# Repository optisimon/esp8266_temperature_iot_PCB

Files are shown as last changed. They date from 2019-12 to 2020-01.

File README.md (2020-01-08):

# esp8266_temperature_iot_PCB

This is the PCB portion of the temperature plotting iot project.

Project homepage: https://optisimon.com/esp8266/arduino/temperature/monitoring/2020/01/07/esp8266-temperature-plotting-iot/

Software portion: https://github.com/optisimon/esp8266_temperature_iot

Hardware portion: https://github.com/optisimon/esp8266_temperature_iot_PCB/

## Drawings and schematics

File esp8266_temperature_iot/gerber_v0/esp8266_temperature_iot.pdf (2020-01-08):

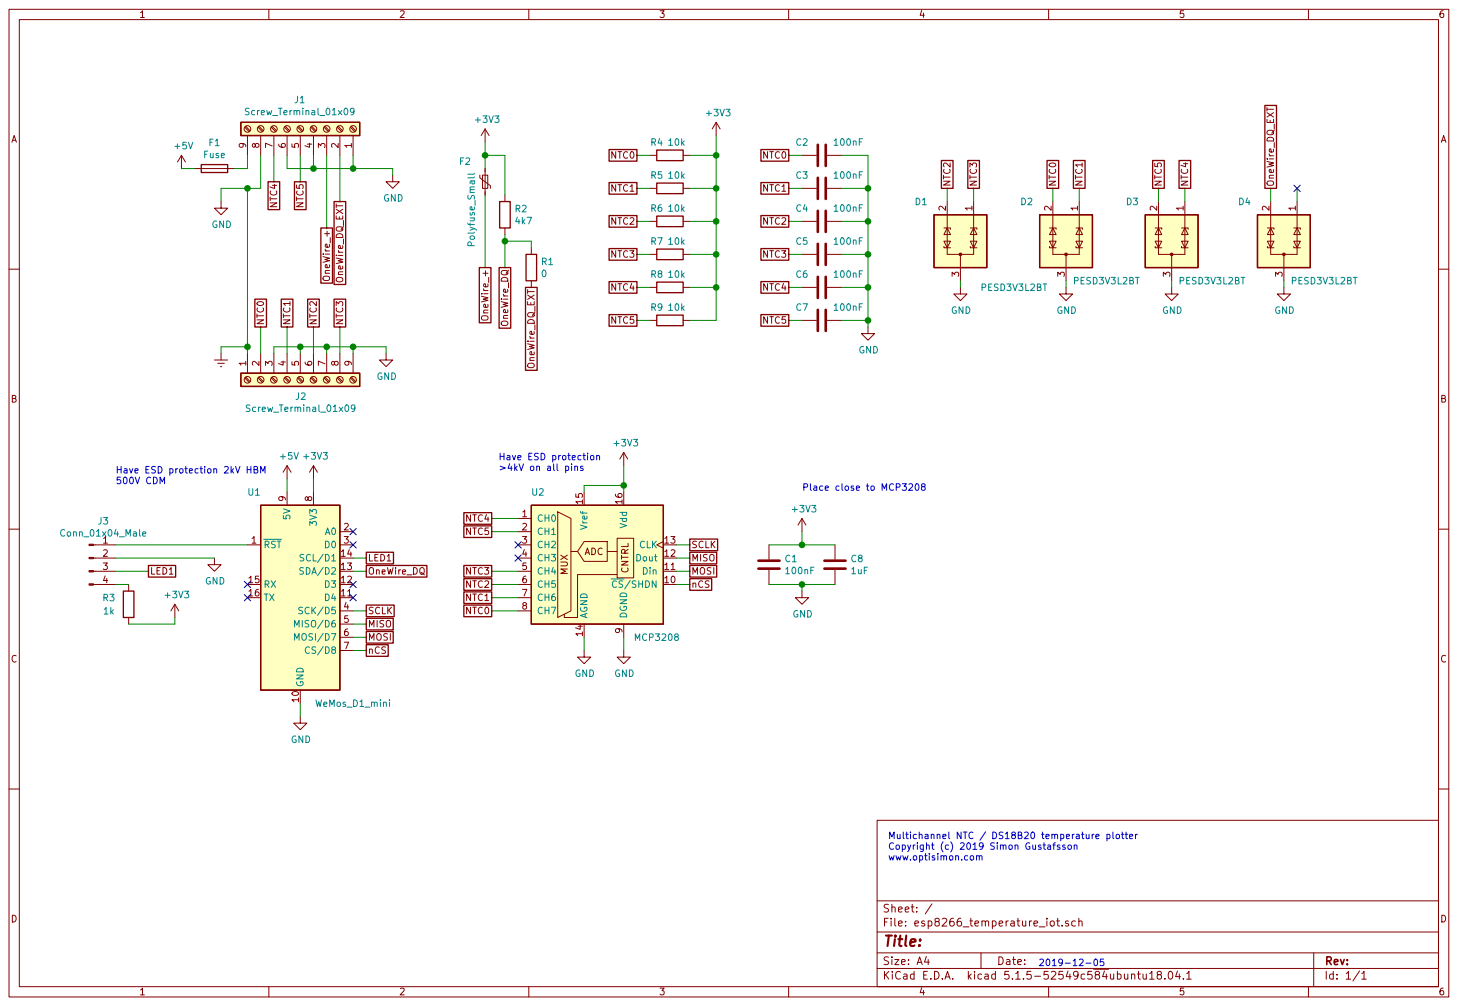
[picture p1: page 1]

Place close to MCP3208 Have ESD protection 2kV HBM
500V CDM

Multichannel NTC / DS18B20 temperature plotter
Copyright (c) 2019 Simon Gustafsson
www.optisimon.com

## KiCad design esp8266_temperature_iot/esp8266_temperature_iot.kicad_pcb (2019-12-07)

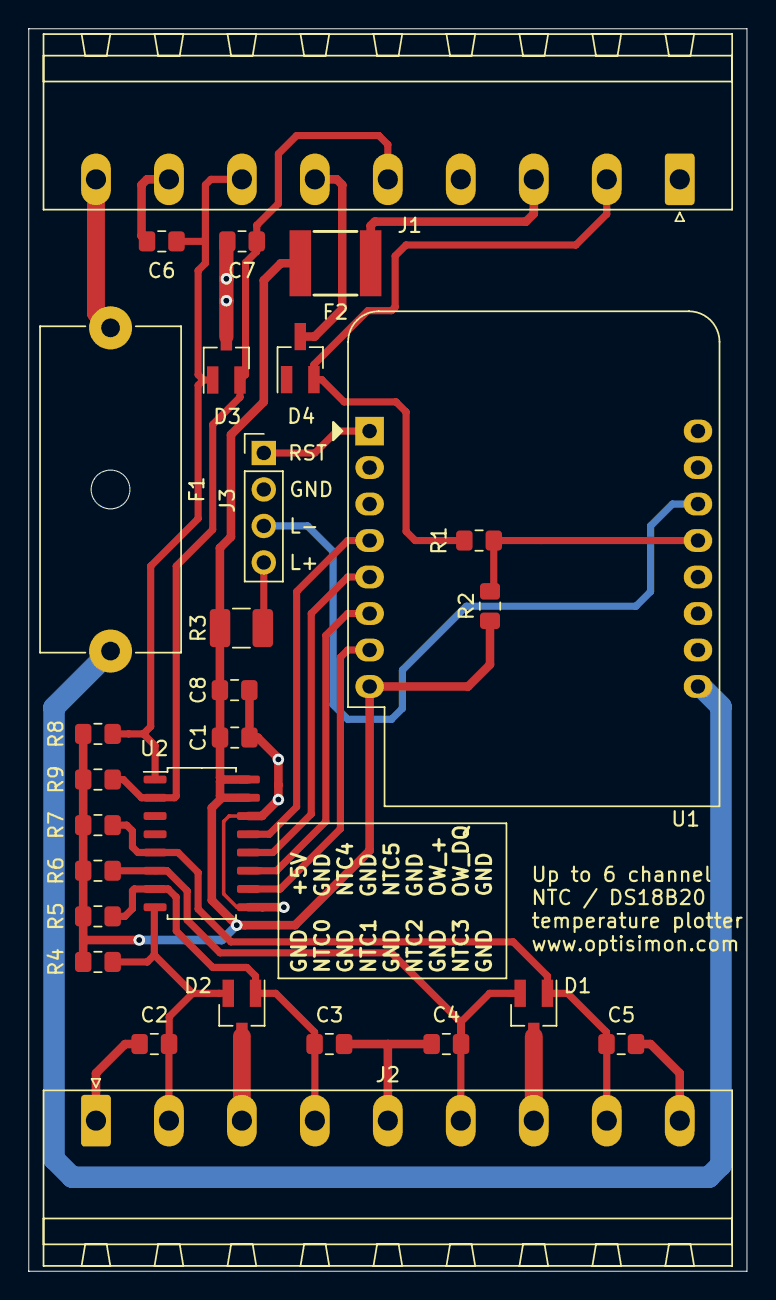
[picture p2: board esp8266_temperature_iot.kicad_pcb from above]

Board: 2 copper layers, 50.0 x 86.5 mm, 28 parts (0 on the bottom side), 20 nets.

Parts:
C1, C2, C3, C4, C5, C6, C7: 100nF; C_0805_2012Metric_Pad1.15x1.40mm_HandSolder
C8: 1uF; C_0805_2012Metric_Pad1.15x1.40mm_HandSolder
D1, D2, D3, D4: PESD3V3L2BT; SOT-23_Handsoldering
F1: Fuse; Fuseholder_Cylinder-5x20mm_Schurter_0031_8201_Horizontal_Op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
F2: Polyfuse_Small; Fuse_Littlefuse-2016L
J1, J2: Screw_Terminal_01x09; PhoenixContact_MSTBA_2,5_9-G-5,08_1x09_P5.08mm_Horizontal
J3: Conn_01x04_Male; PinHeader_1x04_P2.54mm_Vertical
R1: 270; R_0805_2012Metric_Pad1.15x1.40mm_HandSolder
R2: 4k7; R_0805_2012Metric_Pad1.15x1.40mm_HandSolder
R3: 1k; R_1210_3225Metric_Pad1.42x2.65mm_HandSolder
R4, R5, R6, R7, R8, R9: 10k; R_0805_2012Metric_Pad1.15x1.40mm_HandSolder
U1: WeMos_D1_mini; WEMOS_D1_mini_light
U2: MCP3208; SOIC-16_4.55x10.3mm_P1.27mm

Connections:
+3V3: C1.1, C8.1, F2.2, R2.1, R3.2, R4.1, R5.1, R6.1, R7.1, R8.1, R9.1, U1.8, U2.15, U2.16
+5V: F1.2, U1.9
Earth: C1.2, C2.1, C3.1, C4.1, C5.1, C6.1, C7.1, C8.2, D1.3, D2.3, D3.3, D4.3, J1.1, J1.4, J1.6, J1.8, J2.1, J2.3, J2.5, J2.7, J2.9, J3.2, U1.10, U2.9, U2.14
LED1: J3.3, U1.14
MISO: U1.5, U2.12
MOSI: U1.6, U2.11
NTC0: C2.2, D2.2, J2.2, R4.2, U2.8
NTC1: C3.2, D2.1, J2.4, R5.2, U2.7
NTC2: C4.2, D1.2, J2.6, R6.2, U2.6
NTC3: C5.2, D1.1, J2.8, R7.2, U2.5
NTC4: C6.2, D3.1, J1.7, R8.2, U2.1
NTC5: C7.2, D3.2, J1.5, R9.2, U2.2
unnamed: F1.1, J1.9
unnamed: J3.1, U1.1
unnamed: J3.4, R3.1
OneWire_+: F2.1, J1.3
OneWire_DQ: R1.1, R2.2, U1.13
OneWire_DQ_EXT: D4.2, J1.2, R1.2
SCLK: U1.4, U2.13
nCS: U1.7, U2.10

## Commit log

2019-12-04 Schematic and rough routing
    [esp8266_temperature_iot.kicad_pcb, esp8266_temperature_iot.sch]
2019-12-05 Nicer looking PCB (thicker wires + ground pour)
    [esp8266_temperature_iot.kicad_pcb]
2019-12-05 Even nicer - everything double checked. Ready for order
    [esp8266_temperature_iot.kicad_pcb, esp8266_temperature_iot.sch]
2019-12-07 Gerbers / drill file sent in order
2019-12-07 Not sure what was changed if anything
    [esp8266_temperature_iot.kicad_pcb]
2020-01-08 Gerbers and schematic as ordered and populated
    [esp8266_temperature_iot-B_Cu.gbr, esp8266_temperature_iot-B_Mask.gbr, esp8266_temperature_iot-Edge_Cuts.gbr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]
